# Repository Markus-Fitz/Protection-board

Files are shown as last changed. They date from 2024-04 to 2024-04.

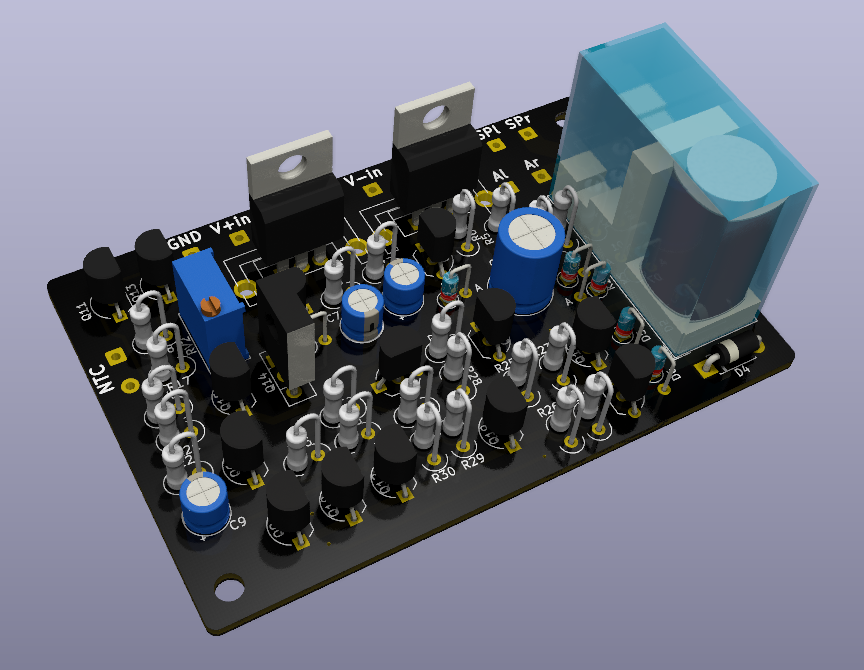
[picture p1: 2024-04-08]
render_top.png

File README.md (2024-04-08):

# Protection-board
 Speaker-protection board for power amplifier.

# Description
 The board includes a relay that connects or disconnects the speakers from the amplifiers. The circuit includes a delay function to avoid initial transients to damage the speakers, a DC-detection to protect the speakers in case of a failing output stage or wrong DC-adjustment and a temperature-sensing circuit which disconnects the speakers from the amplifiers in case of overtemperature.

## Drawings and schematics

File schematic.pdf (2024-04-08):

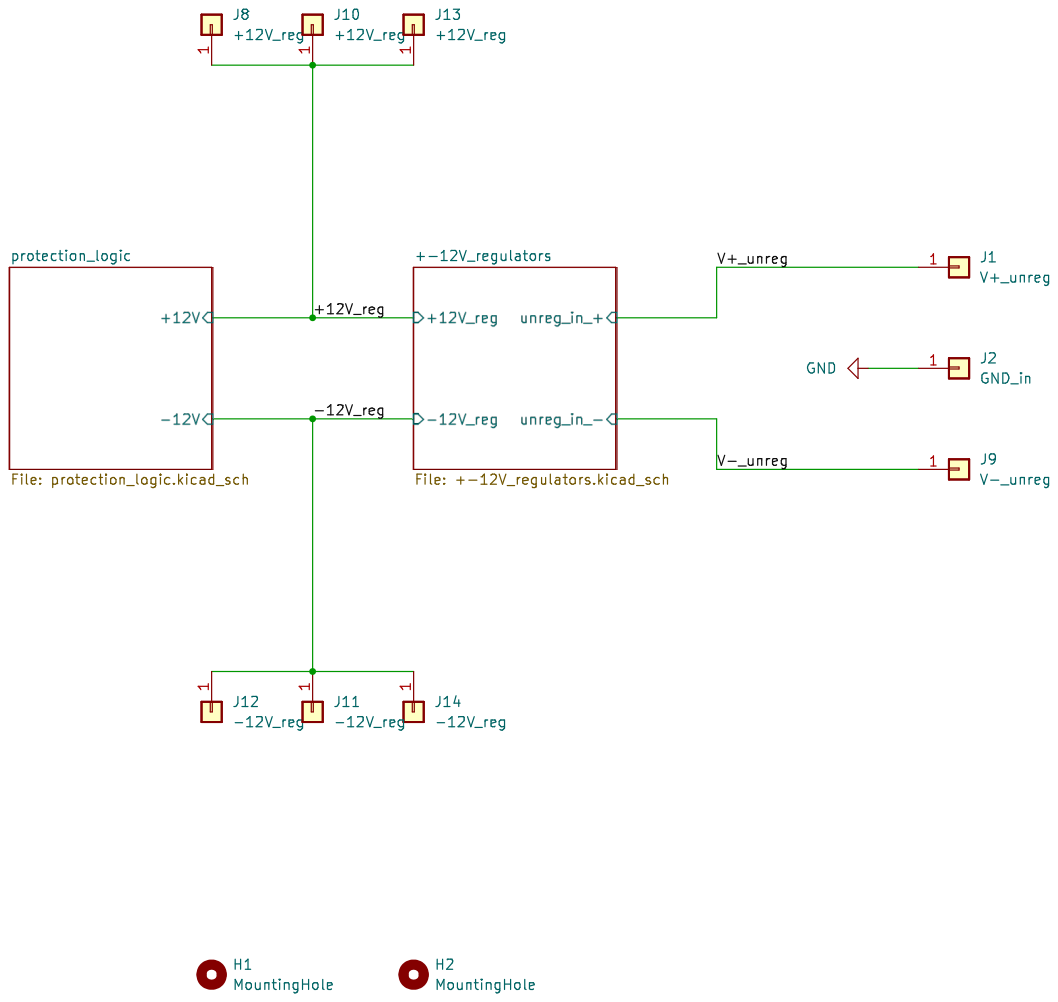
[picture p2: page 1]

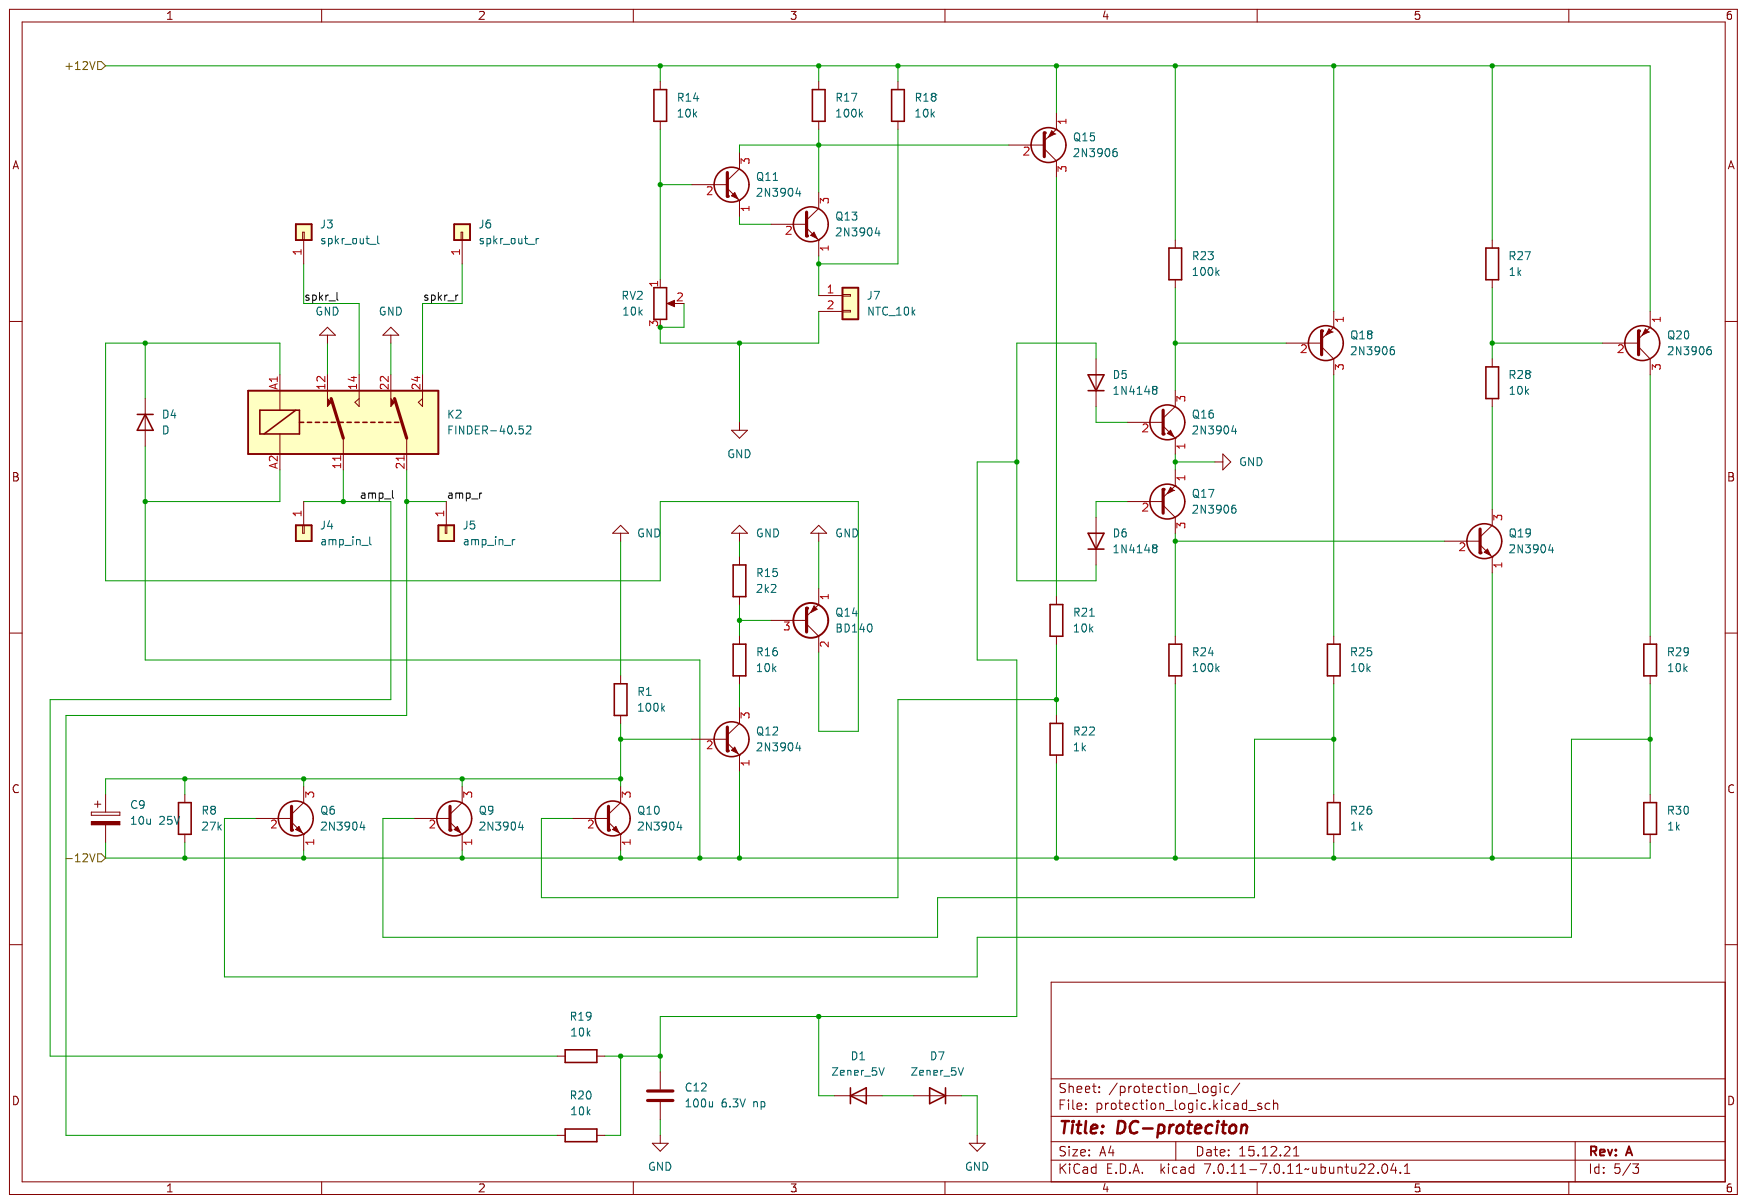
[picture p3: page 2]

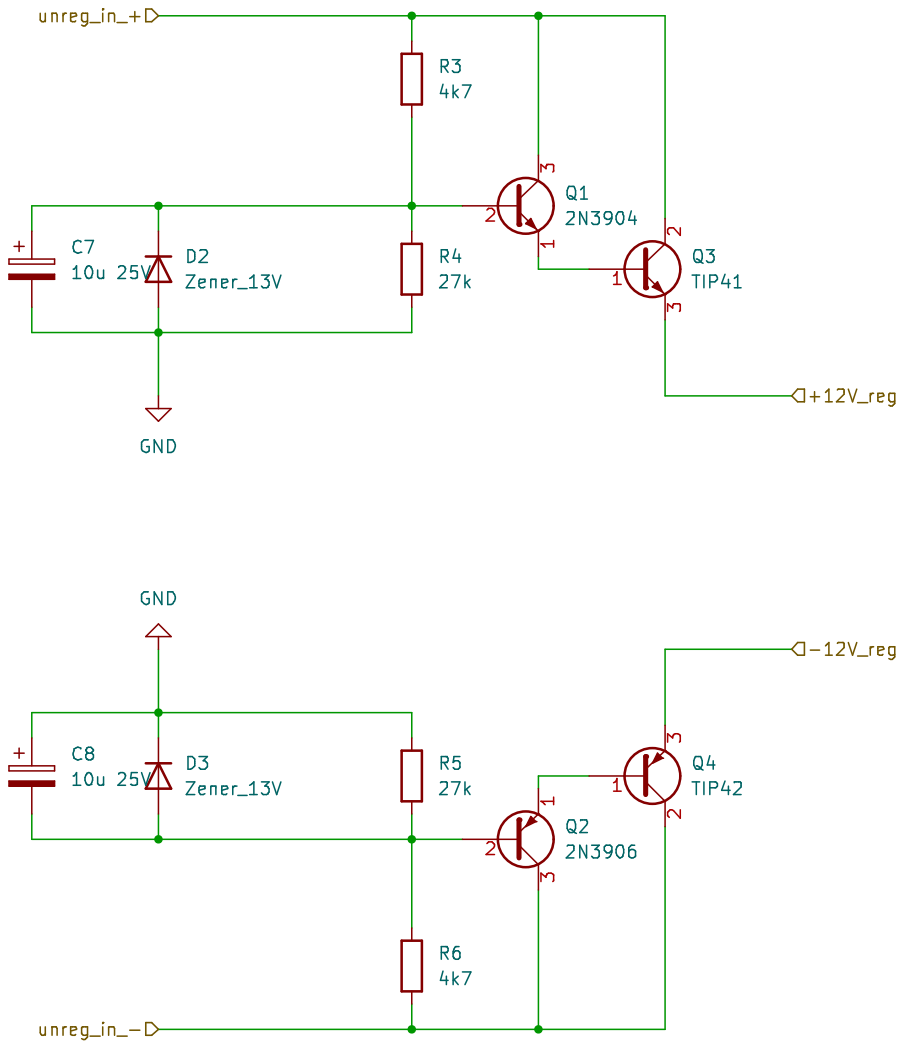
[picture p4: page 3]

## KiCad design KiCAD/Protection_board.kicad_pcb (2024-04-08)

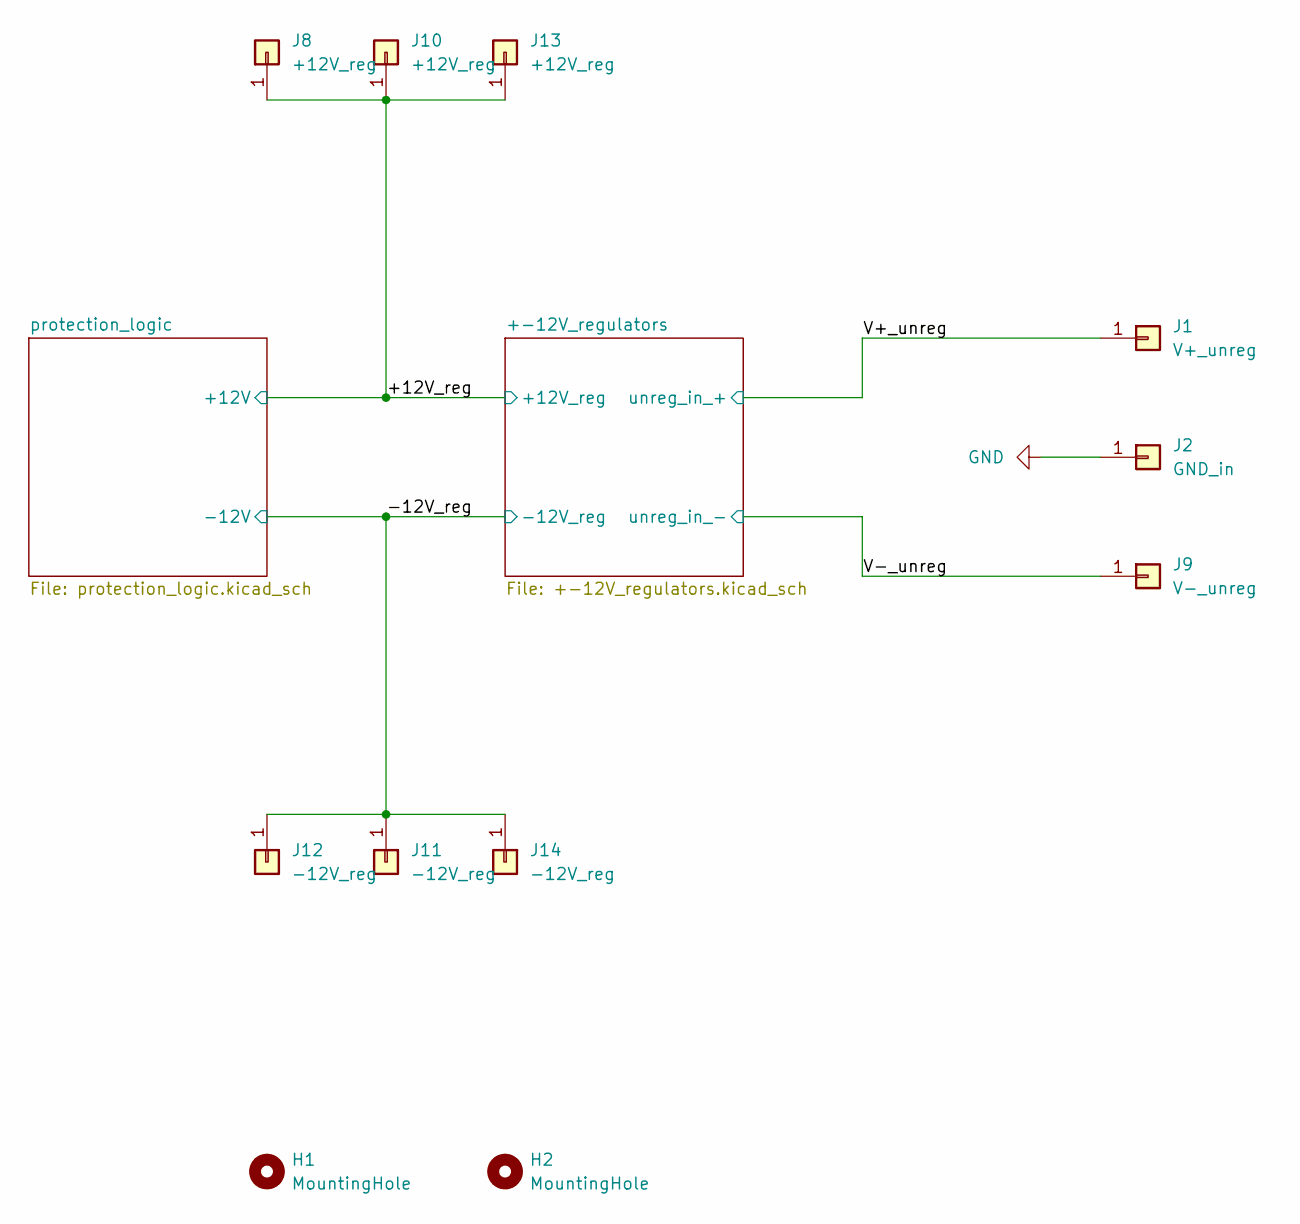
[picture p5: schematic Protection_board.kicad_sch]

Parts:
H1, H2: MountingHole; MountingHole_3.2mm_M3
J1: V+_unreg; SolderWire-0.5sqmm_1x01_D0.9mm_OD2.1mm
J2: GND_in; SolderWire-0.5sqmm_1x01_D0.9mm_OD2.1mm
J8, J10, J13: +12V_reg; SolderWire-0.5sqmm_1x01_D0.9mm_OD2.1mm
J9: V-_unreg; SolderWire-0.5sqmm_1x01_D0.9mm_OD2.1mm
J11, J12, J14: -12V_reg; SolderWire-0.5sqmm_1x01_D0.9mm_OD2.1mm

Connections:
/+12V_reg: J8.1, J10.1, J13.1; also elsewhere on the board
/-12V_reg: J11.1, J12.1, J14.1; also elsewhere on the board
/V+_unreg: J1.1; also elsewhere on the board
/V-_unreg: J9.1; also elsewhere on the board
GND: J2.1; also elsewhere on the board

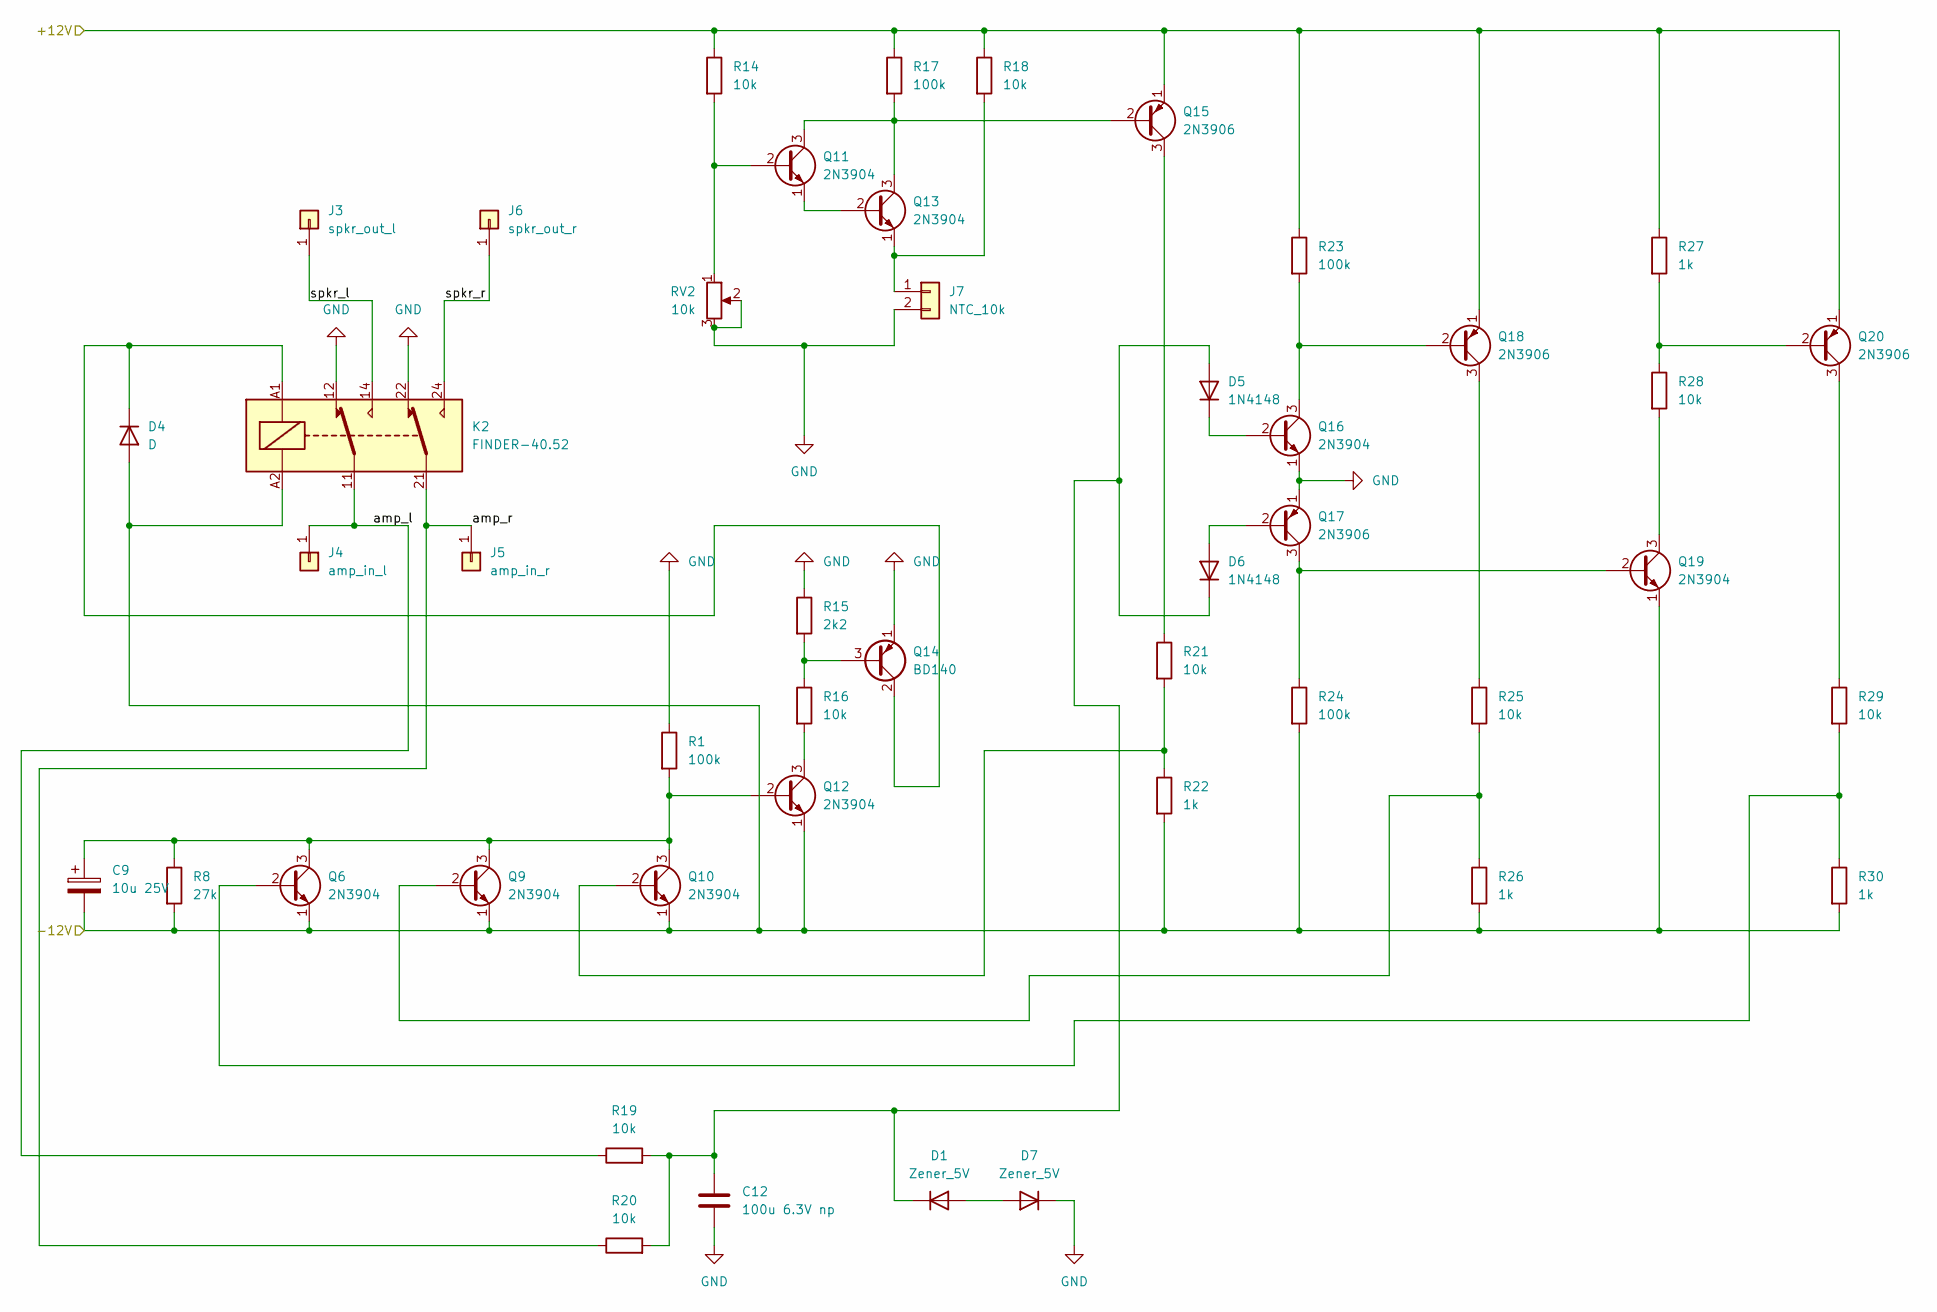
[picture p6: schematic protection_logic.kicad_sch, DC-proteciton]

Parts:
C9: 10u 25V; CP_Radial_D5.0mm_P2.00mm
C12: 100u 6.3V np; C_Radial_D8.0mm_H11.5mm_P3.50mm
D1, D7: Zener_5V; D_DO-35_SOD27_P2.54mm_Vertical_AnodeUp
D4: D; D_DO-41_SOD81_P7.62mm_Horizontal
D5, D6: 1N4148; D_DO-35_SOD27_P2.54mm_Vertical_AnodeUp
J3: spkr_out_l; SolderWire-0.5sqmm_1x01_D0.9mm_OD2.1mm
J4: amp_in_l; SolderWire-0.5sqmm_1x01_D0.9mm_OD2.1mm
J5: amp_in_r; SolderWire-0.5sqmm_1x01_D0.9mm_OD2.1mm
J6: spkr_out_r; SolderWire-0.5sqmm_1x01_D0.9mm_OD2.1mm
J7: NTC_10k; SolderWire-0.5sqmm_1x02_P4.6mm_D0.9mm_OD2.1mm
K2: FINDER-40.52; Relay_DPDT_Finder_40.52
Q6, Q9, Q10, Q11, Q12, Q13, Q16, Q19: 2N3904; TO-92_Inline_Wide
Q14: BD140; TO-126-3_Vertical
Q15, Q17, Q18, Q20: 2N3906; TO-92_Inline_Wide
R1, R17, R23, R24: 100k; r_vertical_symm
R8: 27k; r_vertical_symm
R14, R16, R18, R19, R20, R21, R25, R28, R29: 10k; r_vertical_symm
R15: 2k2; r_vertical_symm
R22, R26, R27, R30: 1k; r_vertical_symm
RV2: 10k; Potentiometer_Bourns_3296W_Vertical

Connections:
/+12V_reg: Q15.1 (E), Q18.1 (E), Q20.1 (E), R14.1, R17.1, R18.1, R23.1, R27.1; also elsewhere on the board
/-12V_reg: C9.2, D4.2 (A), K2.A2, Q6.1 (E), Q9.1 (E), Q10.1 (E), Q12.1 (E), Q19.1 (E), R8.2, R22.2, R24.2, R26.2, R30.2; also elsewhere on the board
/protection_logic/amp_l: J4.1, K2.11, R19.1
/protection_logic/amp_r: J5.1, K2.21, R20.1
/protection_logic/spkr_l: J3.1, K2.14
/protection_logic/spkr_r: J6.1, K2.24
GND: C12.2, D7.1 (K), J7.2, K2.12, K2.22, Q14.1 (E), Q16.1 (E), Q17.1 (E), R1.1, R15.1, RV2.2, RV2.3; also elsewhere on the board
unnamed: C9.1, Q6.3 (C), Q9.3 (C), Q10.3 (C), Q12.2 (B), R1.2, R8.1
unnamed: C12.1, D1.1 (K), D5.2 (A), D6.1 (K), R19.2, R20.2
unnamed: D1.2 (A), D7.2 (A)
unnamed: D4.1 (K), K2.A1, Q14.2 (C)
unnamed: D5.1 (K), Q16.2 (B)
unnamed: D6.2 (A), Q17.2 (B)
unnamed: J7.1, Q13.1 (E), R18.2
unnamed: Q6.2 (B), R29.2, R30.1
unnamed: Q9.2 (B), R25.2, R26.1
unnamed: Q10.2 (B), R21.2, R22.1
unnamed: Q11.1 (E), Q13.2 (B)
unnamed: Q11.2 (B), R14.2, RV2.1
unnamed: Q11.3 (C), Q13.3 (C), Q15.2 (B), R17.2
unnamed: Q12.3 (C), R16.2
unnamed: Q14.3 (B), R15.2, R16.1
unnamed: Q15.3 (C), R21.1
unnamed: Q16.3 (C), Q18.2 (B), R23.2
unnamed: Q17.3 (C), Q19.2 (B), R24.1
unnamed: Q18.3 (C), R25.1
unnamed: Q19.3 (C), R28.2
unnamed: Q20.2 (B), R27.2, R28.1
unnamed: Q20.3 (C), R29.1

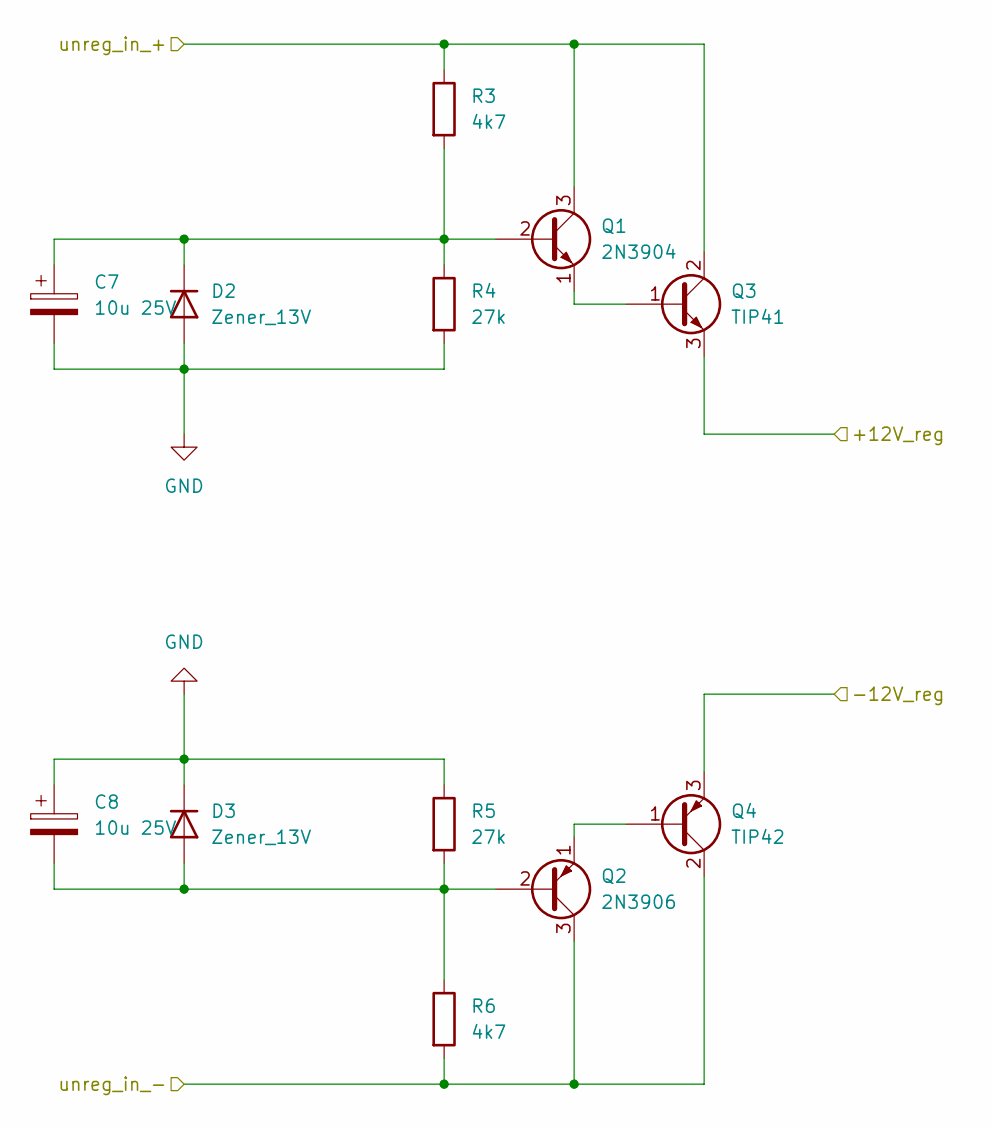
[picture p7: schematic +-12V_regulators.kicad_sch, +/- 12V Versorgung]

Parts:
C7, C8: 10u 25V; CP_Radial_D5.0mm_P2.00mm
D2, D3: Zener_13V; D_DO-35_SOD27_P2.54mm_Vertical_AnodeUp
Q1: 2N3904; TO-92_Inline_Wide
Q2: 2N3906; TO-92_Inline_Wide
Q3: TIP41; TO-220-3_Vertical
Q4: TIP42; TO-220-3_Vertical
R3, R6: 4k7; r_vertical_symm
R4, R5: 27k; r_vertical_symm

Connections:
/+12V_reg: Q3.3 (E); also elsewhere on the board
/-12V_reg: Q4.3 (E); also elsewhere on the board
/V+_unreg: Q1.3 (C), Q3.2 (C), R3.1; also elsewhere on the board
/V-_unreg: Q2.3 (C), Q4.2 (C), R6.2; also elsewhere on the board
GND: C7.2, C8.1, D2.2 (A), D3.1 (K), R4.2, R5.1; also elsewhere on the board
unnamed: C7.1, D2.1 (K), Q1.2 (B), R3.2, R4.1
unnamed: C8.2, D3.2 (A), Q2.2 (B), R5.2, R6.1
unnamed: Q1.1 (E), Q3.1 (B)
unnamed: Q2.1 (E), Q4.1 (B)

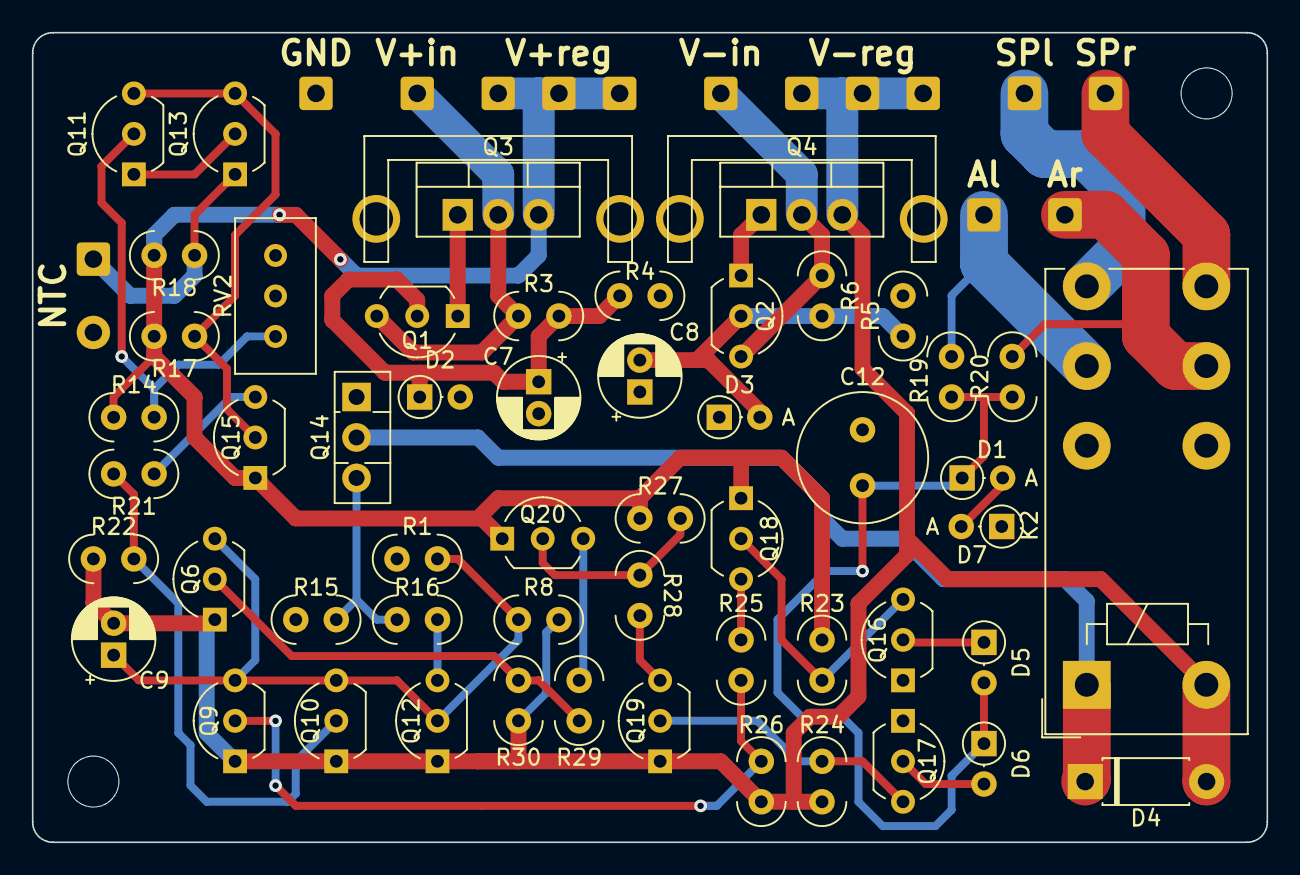
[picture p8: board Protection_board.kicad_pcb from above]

Board: 2 copper layers, 77.5 x 50.8 mm, 69 parts (0 on the bottom side), 35 nets.

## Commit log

2024-04-08 Modified Readme
    Modification of Readme to include circuit description.
2024-04-08 Addition of project files.
    Addition of KiCAD-project and schematic-pdf.
    [+-12V_regulators.kicad_sch, Power_in_softstart.kicad_sch, Protection_board.kicad_pcb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]
2024-04-08 Added render.
    Addition of render of top side of the board.
2024-04-08 Renaming of schematic.
    The german "Schaltplan" was translated to "schematic".
